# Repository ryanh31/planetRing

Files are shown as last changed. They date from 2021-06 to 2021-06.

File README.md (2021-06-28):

# planetRing v3_x
dmx stepper motor control
by ryan h\
for silovsky studios 2021

Lux Phantasmatis / Pavel Zustiak and Keith Skretch

Please refer to the included information guide for setup and use examples

Arduino Uno

DMX shield: https://www.digikey.com/en/products/detail/dfrobot/DFR0260/7087143 \
Dmx Serial Library: https://github.com/mathertel/DMXSerial \
based on this: https://sourceforge.net/projects/dmxlibraryforar/files/ \
arduino code provided 

Stepper Control using the AccelStepper Library: https://www.airspayce.com/mikem/arduino/AccelStepper/ \
Stepper Driver: DM860T https://www.omc-stepperonline.com/download/DM860T.pdf \
Stepper Motor: 34HE59-6004S https://www.omc-stepperonline.com/download/34HE59-6004S.pdf 

Limit switching / Auto Homing control using 8mm Magnetic Proximity Sensors: MAE-AP-1A \
https://cdn.automationdirect.com/static/specs/ip69kproxmag1218maf.pdf 

Software interface for Isadora 3.x & DMX with Lanbox or Enttec USB DMX \
Isadora Motor Control Index Patch provided.

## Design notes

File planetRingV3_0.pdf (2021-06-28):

# planetRing

## INFO GUIDE

planetRing-dmx stepper v3.0

Silovsky Studios 2021

## Planet/Ring Stepper Motor Control System with DMX512 & LED Control via Artnet

Software: Isadora 3.0 and Madmapper

info guide, code, hardware and controller system design by Ryan Holsopple
ryan.local@gmail.com

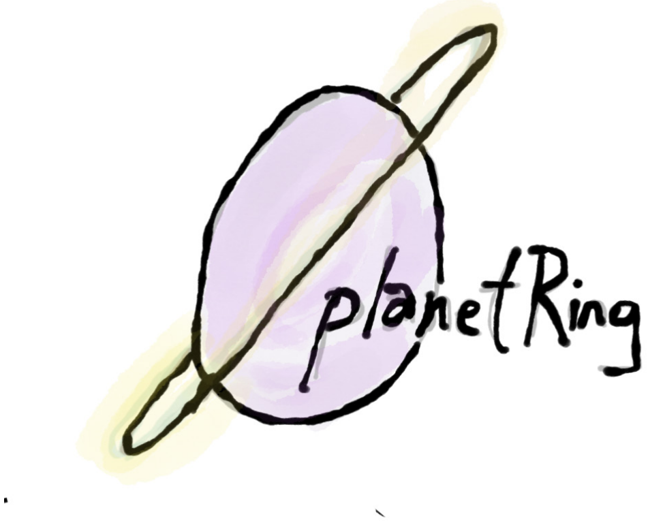
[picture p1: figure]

# Information Guide Index

### Part 1: DMX to Stepper Motor Control

System Diagram
DMX Wiring Diagram
Wiring Color Codes

Modes

Isadora Control

### Part 2: Artnet31 Network Information

Login and SSID information

LeDMX King

Artnet Information and Setup with MadMapper (TBD)

Isadora Syphon to MadMapper

### Part 3: Troubleshooting (working)

# Part 1: Stepper Motor Control with DMX system diagram

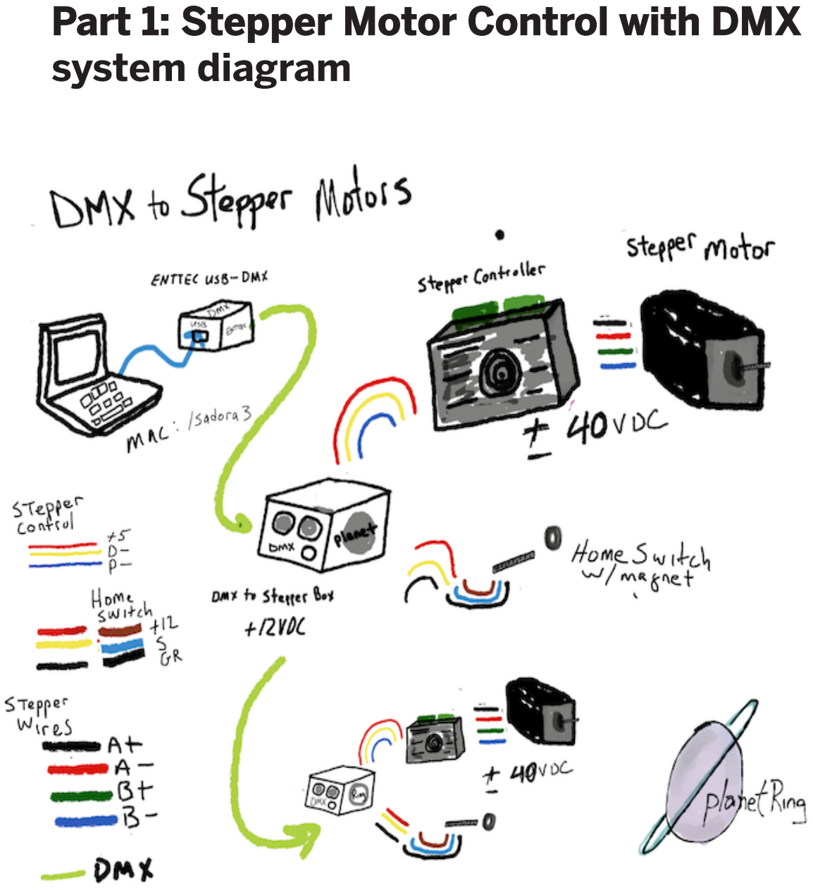
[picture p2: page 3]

# Stepper Motor Control with DMX DMX wiring diagram

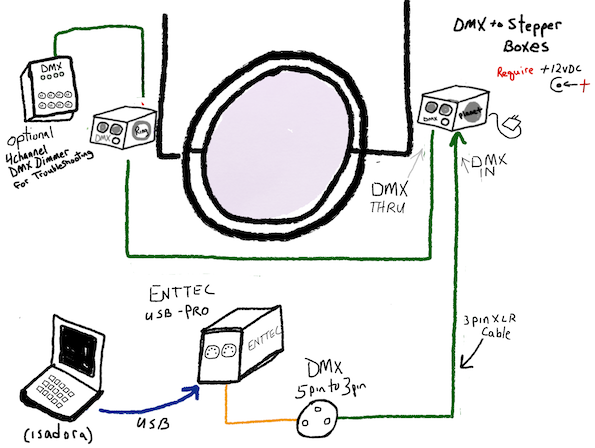
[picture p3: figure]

Stepper motor data sheet:
https://www.omc-stepperonline.com/download/34HE59-6004S.pdf

Stepper driver: DM860T https://www.omc-stepperonline.com/download/DM860T.pdf

Dip Switch Settings: 800 Steps, full power

1=OFF, 2=ON, 3=OFF, 4=ON, 5=OFF, 6=ON, 7=ON, 8=ON

WIRING COLOR SCHEMES
Stepper Controller, this is the same wiring for both motors.

Stepper MOTOR Controller (Black box with Fan):

Color code connections from Arduino Box to Stepper Controller

DIR- Yellow
DIR+ Red
PUL- Blue
PUL+ Red

Color code connections from Stepper Controller to MOTOR

A+ Black
A- Green
B+ Red
B- Blue
+ 45 vdc
- Ground

Home Position Proximity Sensor

Color code connections from Arduino Box to Stepper Controller

Red to Brown
Black to Black
Yellow to Blue

# Technical Info and Wiring Color Codes

# Wiring and Dip Switch Photos

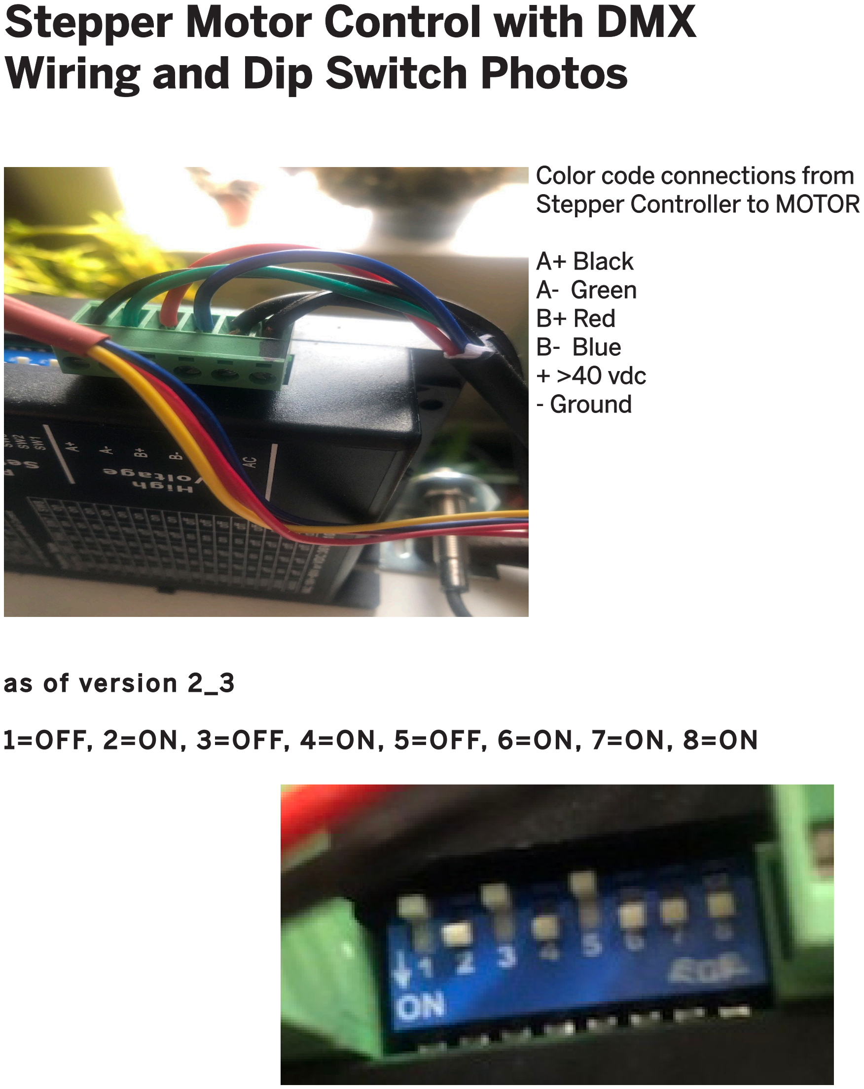
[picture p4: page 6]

Color code connections from Stepper Controller to MOTOR

A+ Black
A- Green
B+ Red
B- Blue
+ >40 vdc
- Ground

as of version 2_3

1=OFF, 2=ON, 3=OFF, 4=ON, 5=OFF, 6=ON, 7=ON, 8=ON

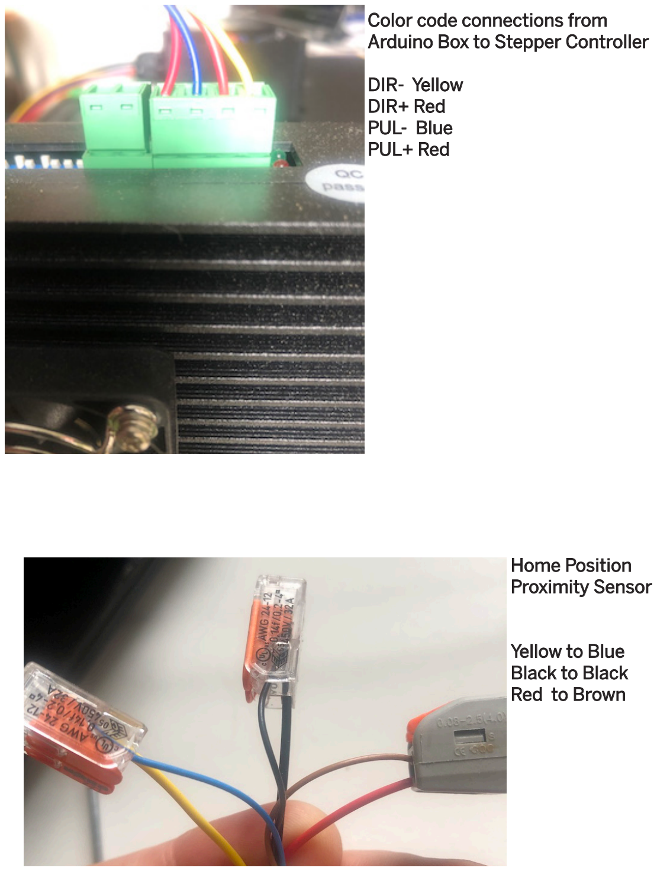
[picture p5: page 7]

Color code connections from Arduino Box to Stepper Controller

DIR- Yellow
DIR+ Red
PUL- Blue
PUL+ Red

Home Position
Proximity Sensor

Yellow to Blue
Black to Black
Red to Brown

# Stepper Motor Control

### with DMX in SITU

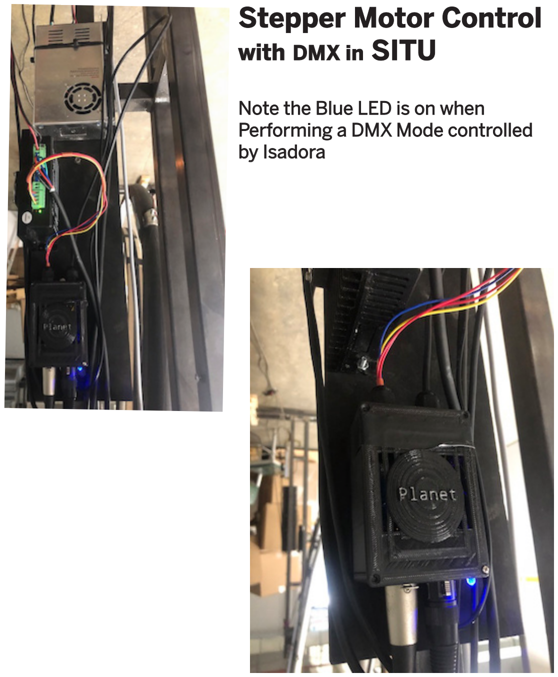
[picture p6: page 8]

Note the Blue LED is on when Performing a DMX Mode controlled by Isadora

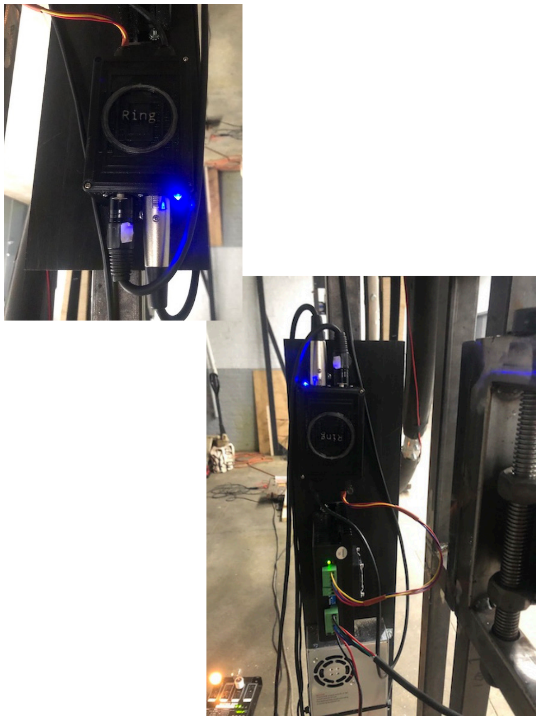
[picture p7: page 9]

Modes for PLANET / RING Motors

Mode 0: Stop Motors

Mode 1: Auto Home, rotate to home position
(planet and Ring Autohome in opposite directions)

Mode 2: Do 1 rotation with acceleration and deceleration
(in beta, count is not correct)

Mode 3: Do X rotations with acceleration/deceleration, where X is your value (in beta, count is not correct)

Mode 4: Accelerate to constant speed CW X, then, when triggered, back to stop, where X > 0 && <= full speed

Mode 5: Accelerate to constant speed Full Speed CCW X, then, when triggered, back to stop, where X > 0 && <= full speed

Mode 6: Accelerate to constant speed FUll Speed CW X, then, when triggered, back to stop, where X > 0 && <= full speed

Mode 7: Accelerate to constant speed CCW X, then, when triggered, back to stop, where X > 0 && <= full speed

Mode 8. Live Mode with Dynamic Position Control
Move to specific cardinal points, or degrees in between

Mode 9: Accelerate to Speed CW, Live Control
(in beta, ramping is unstable for faster speeds)

Mode 10 Accelerate to Speed CCW, Live Control

Transmit DMX with Isadora and an ENTTEC DMX USB Interface:

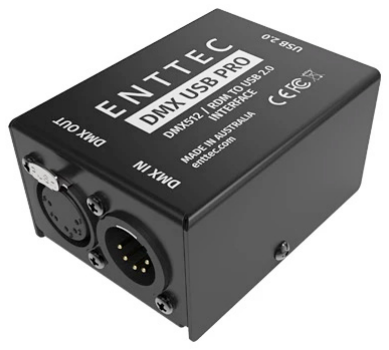
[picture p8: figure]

https://www.enttec.com/product/lighting-communication-protocols/dmx512/dmx-usb-interface/

To send DMX with Isadora using an Enttec DMX USB Pro:

Select and Enable the Device in the menu:

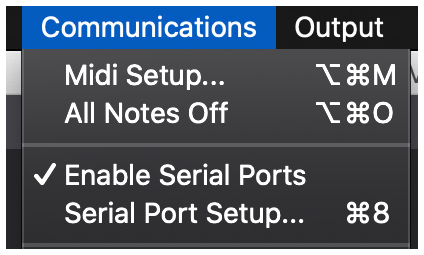
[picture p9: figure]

Communications>Serial Port Setup...

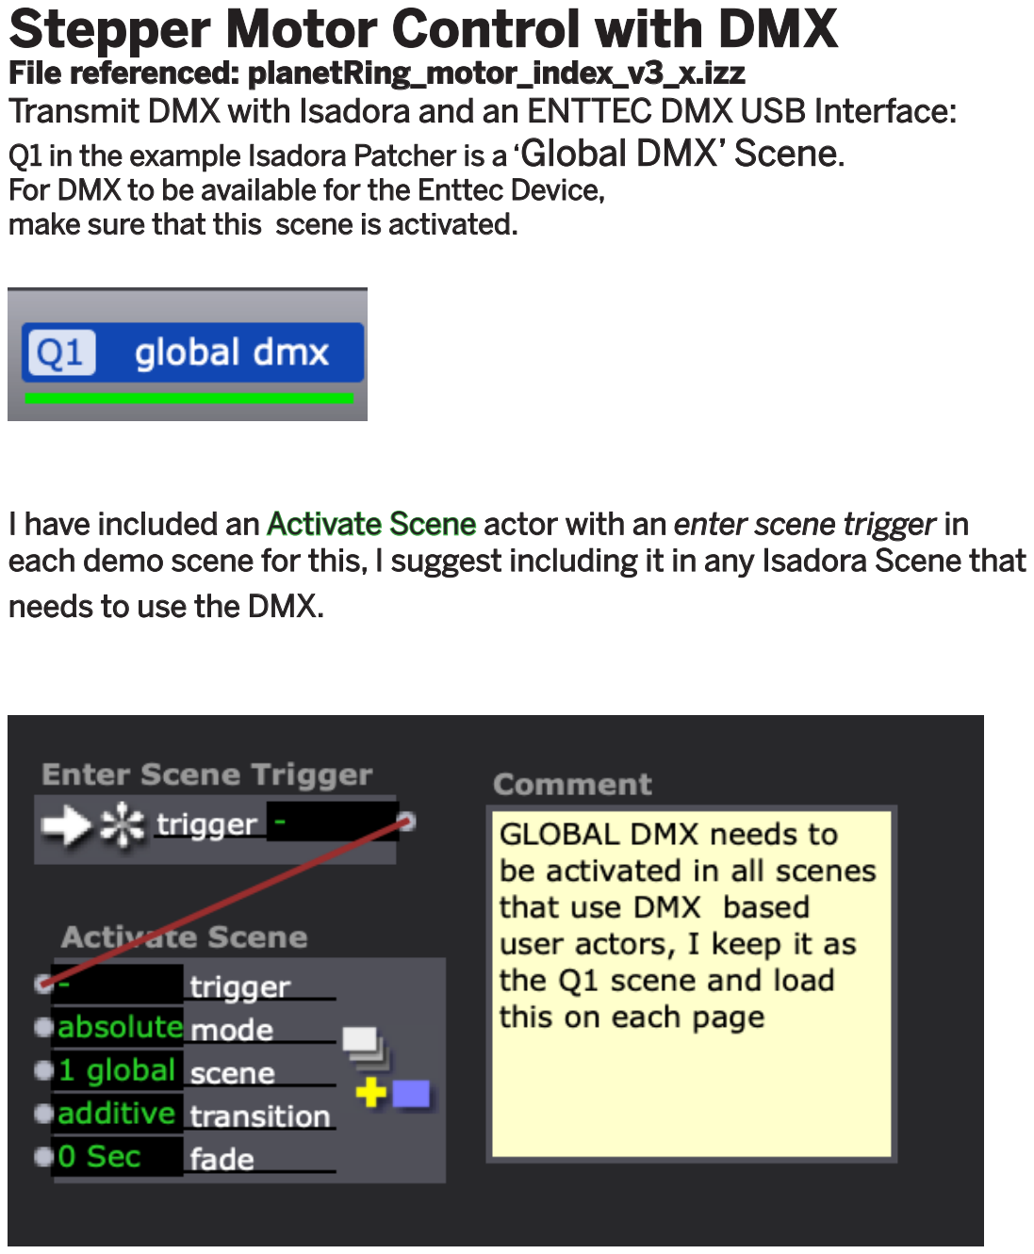
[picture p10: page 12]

File referenced: planetRing_motor_index_v3_x.izz
Transmit DMX with Isadora and an ENTTEC DMX USB Interface: Q1 in the example Isadora Patcher is a ‘Global DMX’ Scene.
For DMX to be available for the Enttec Device,
make sure that this scene is activated.

I have included an Activate Scene actor with an enter scene trigger in each demo scene for this, I suggest including it in any Isadora Scene that needs to use the DMX.

### Isadora Control

All Control Modes are encapsulated into Isadora User Actors.
Please DO NOT EDIT these User Actors, they have timing and values that are specific to the whole system.
These User Actors are labled and have an ENABLE input.
There are User Actors for each device PLANET / RING

NOTE: Only ONE User Actor for each device may be Enabled at the same time for the device to work Properly. If using multiple modes in one scene, make sure to enable/disable the User Actors as necessary. To make this easier I have included a Mode Stop/Start User actor. Remember to set the Enable State and to trigger the user actor.

### Mode 0: Stop Motors

Each example Scene (“Q”) that I provide uses an Enter Scene Trigger to Stop the Stepper motors.

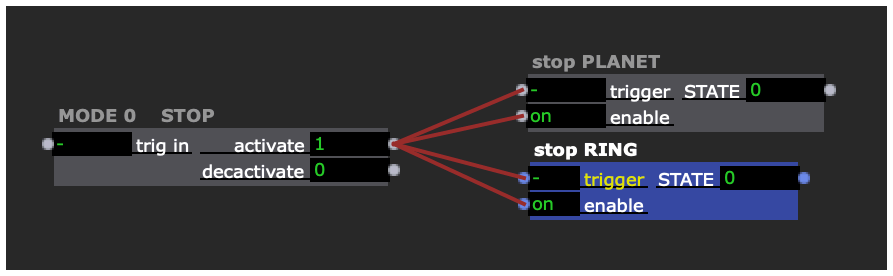
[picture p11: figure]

### Example Scene Q2:

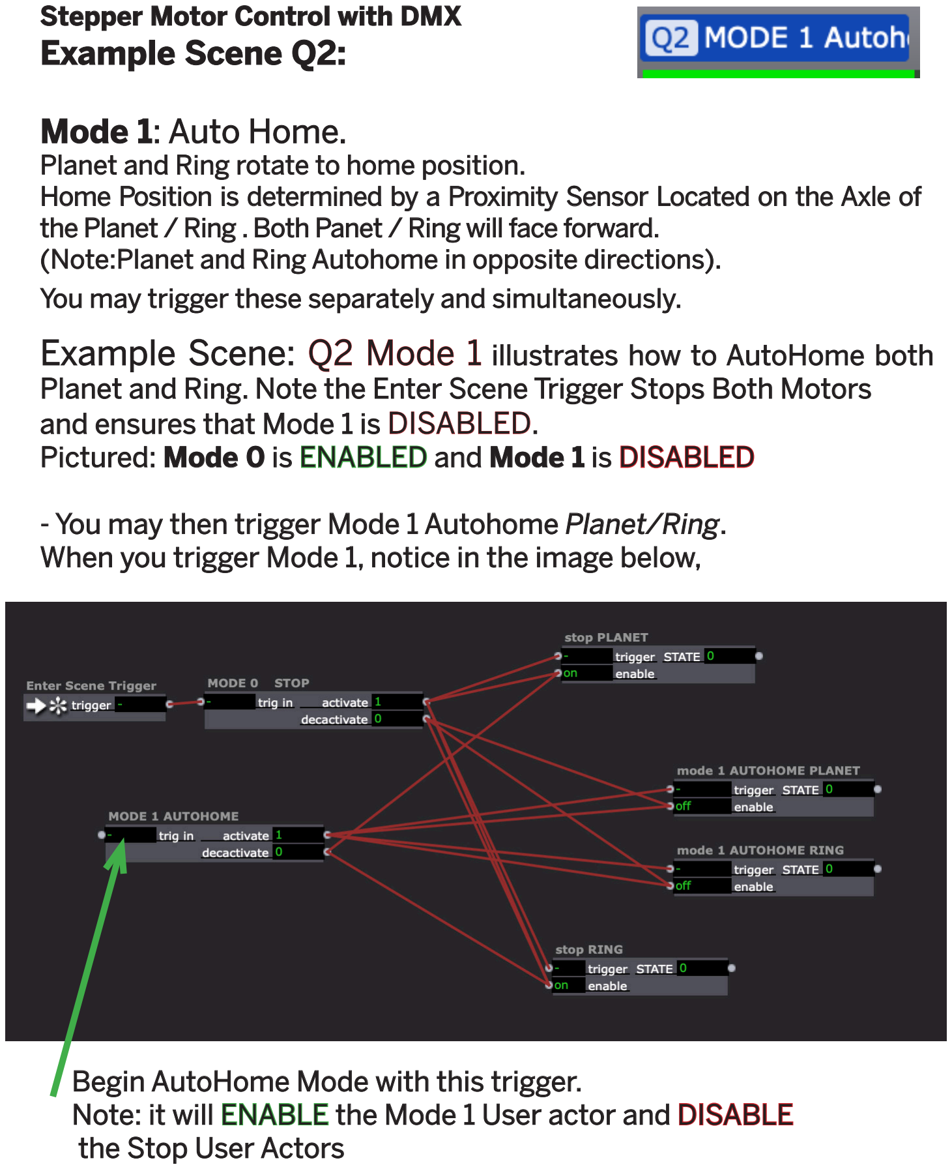
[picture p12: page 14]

Mode 1: Auto Home.
Planet and Ring rotate to home position.
Home Position is determined by a Proximity Sensor Located on the Axle of the Planet / Ring . Both Panet / Ring will face forward.
(Note:Planet and Ring Autohome in opposite directions).
You may trigger these separately and simultaneously.
Example Scene: Q2 Mode 1 illustrates how to AutoHome both Planet and Ring. Note the Enter Scene Trigger Stops Both Motors and ensures that Mode 1 is DISABLED.
Pictured: Mode 0 is ENABLED and Mode 1 is DISABLED
- You may then trigger Mode 1 Autohome Planet/Ring.
When you trigger Mode 1, notice in the image below,

Begin AutoHome Mode with this trigger.
Note: it will ENABLE the Mode 1 User actor and DISABLE the Stop User Actors

### Example Scene Q3:

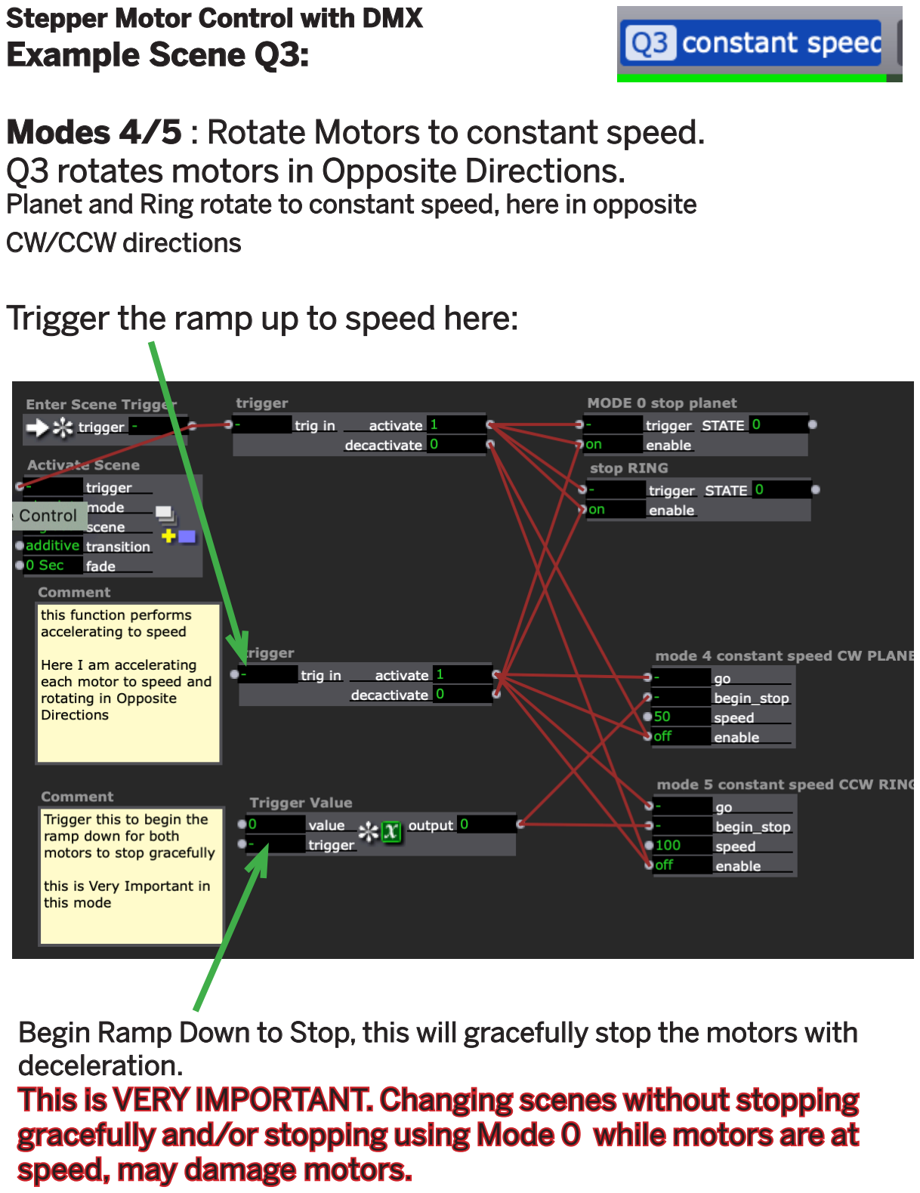
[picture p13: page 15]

Modes 4/5 : Rotate Motors to constant speed. Q3 rotates motors in Opposite Directions.
Planet and Ring rotate to constant speed, here in opposite CW/CCW directions

### Trigger the ramp up to speed here:

Begin Ramp Down to Stop, this will gracefully stop the motors with deceleration.
This is VERY IMPORTANT. Changing scenes without stopping gracefully and/or stopping using Mode 0 while motors are at speed, may damage motors.

### Example Scene Q4:

Modes 4/4: Rotate Motors in One Direction.
Planet and Ring rotate to constant speed, in the image below notice that both Mode 4 constant speed CW planet/Ring user actors are in use.

### Trigger the ramp up to speed here:

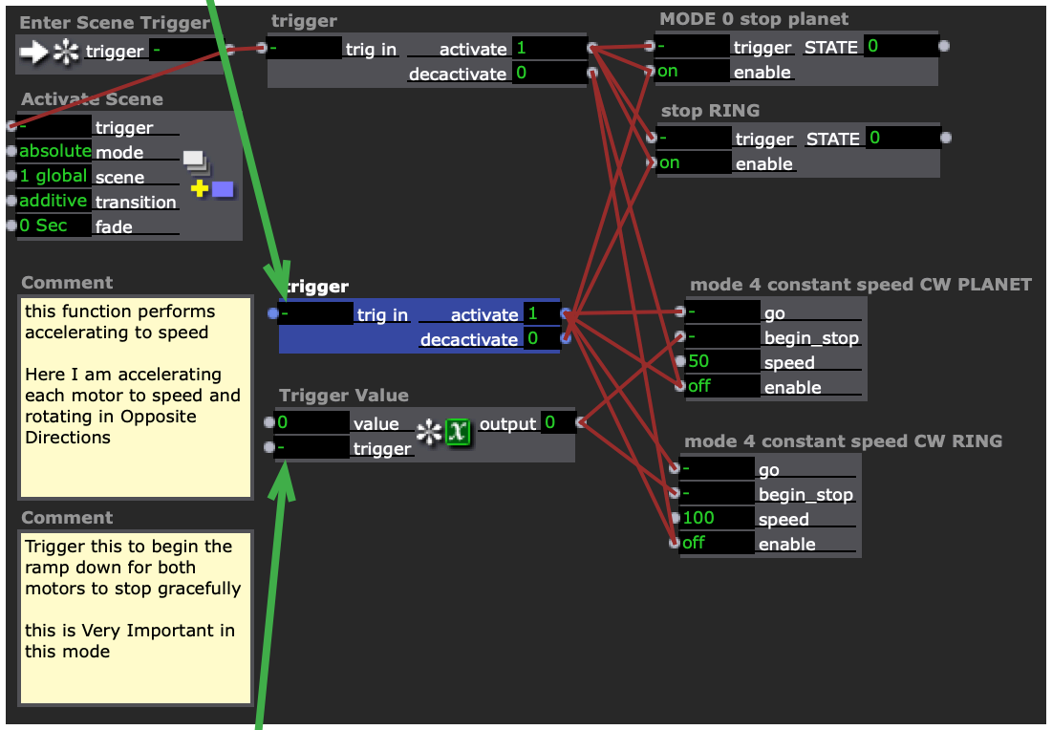
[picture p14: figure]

Begin Ramp Down to Stop, this will gracefully stop the motors with deceleration.
This is VERY IMPORTANT. Changing scenes without stopping gracefully and/or stopping using Mode 0 while motors are at speed, may damage motors.

### Example Scene Q5:

### Mode 8: Live Mode: Dynamic Position Control

Position and acceleration movements are posible on a 0-50.0 scale, floats are possible to acheive smaller steps.

### In the image below of Isadora Scene Q5, an

example of how to use Mode 8 Planet/Ring,

### Isadora Trigger Value actors are used to set positions in

the Mode 8 “position 1-50” user input.

### What I call ‘Cardinal Points’, clock positions are provided

0-3-6-9-12

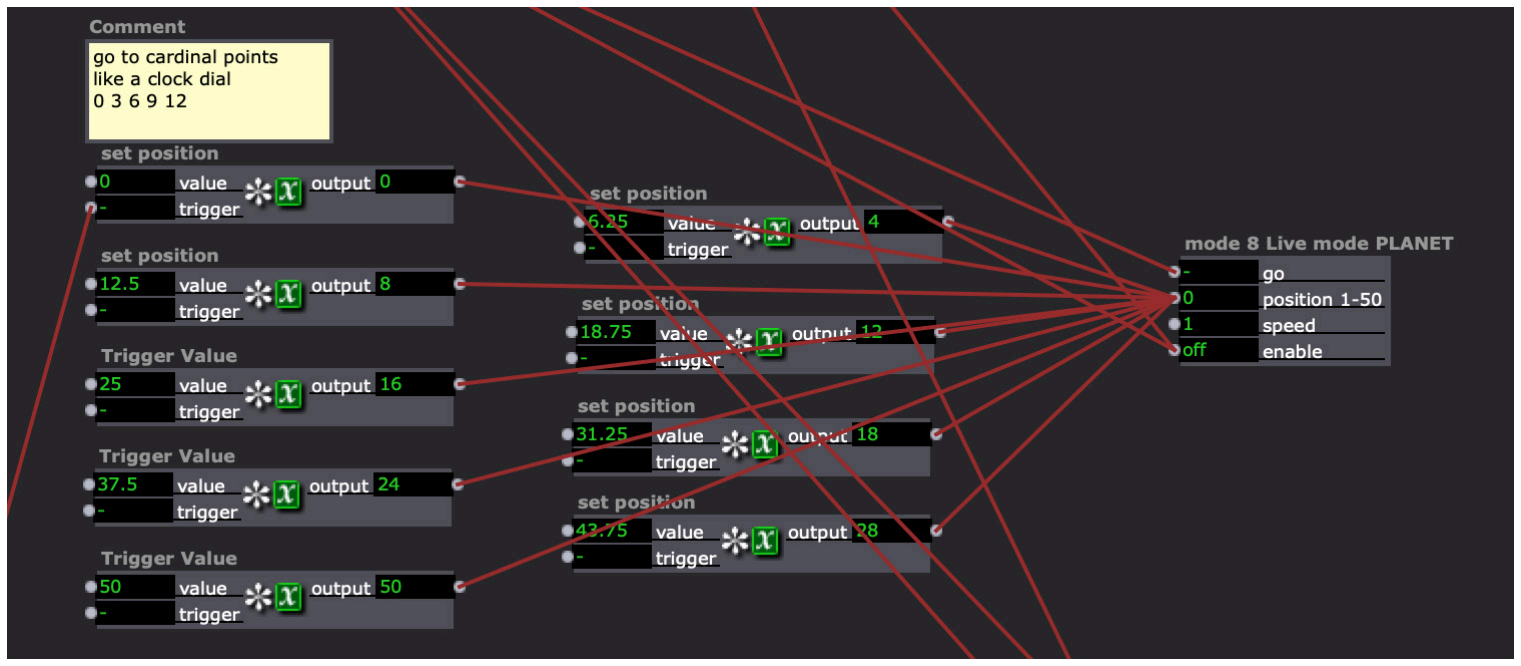
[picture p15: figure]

### Planet / Ring Indexes and DMX Test Mode

The INDEX SCENES Q6/Q7 provide all available Modes.

You can copy / paste these User Actor Modes (1-8) into other scenes, remember to add ENABLE / DISABLE logic to ensure the stepper motors will work correctly.

Modes 0, 1, 4, 5 & 8 have been prioritized for use with the current system.

Note Modes 2, 3, 6, & 7 are not fully developed and in a Beta stage. These MAY be used, but there are a few scaling issues and smoothing issues that make these modes less predictable. If interest in developing these modes increases, we can work to refine.

Test DMX: Scene Q8 acts as a dmx tester, blink channel 4. Use the provided DMX 4channel Dimmer Pack to monitor 4 channels of DMX signal. This Scene blinks channel 4.
NOTE: the DMX address can be changed in isadora and on the dimmer pack if higher channels wish to be chosen.

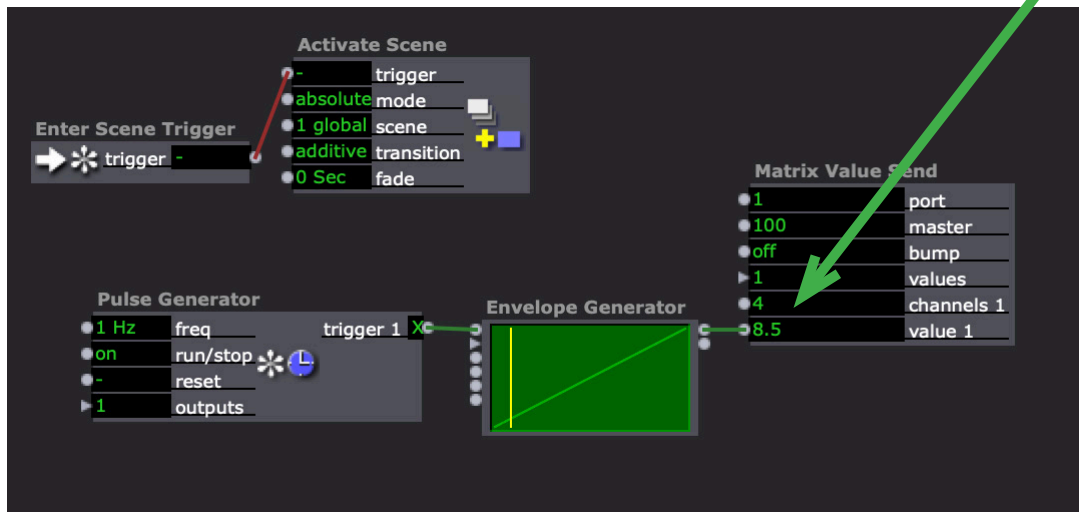
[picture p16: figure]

intentionally left blank

# Part 2: Artnet & Network Information

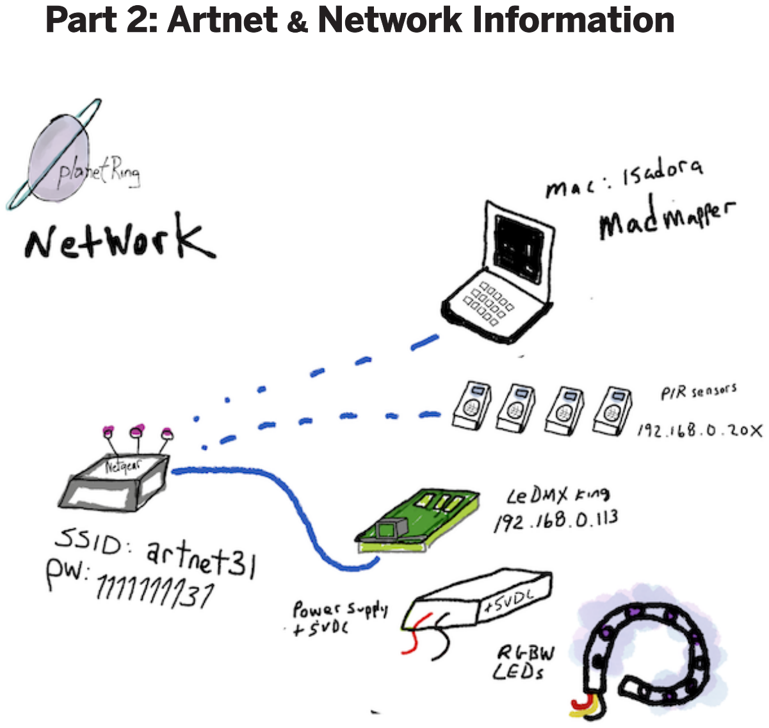
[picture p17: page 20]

# Network Information

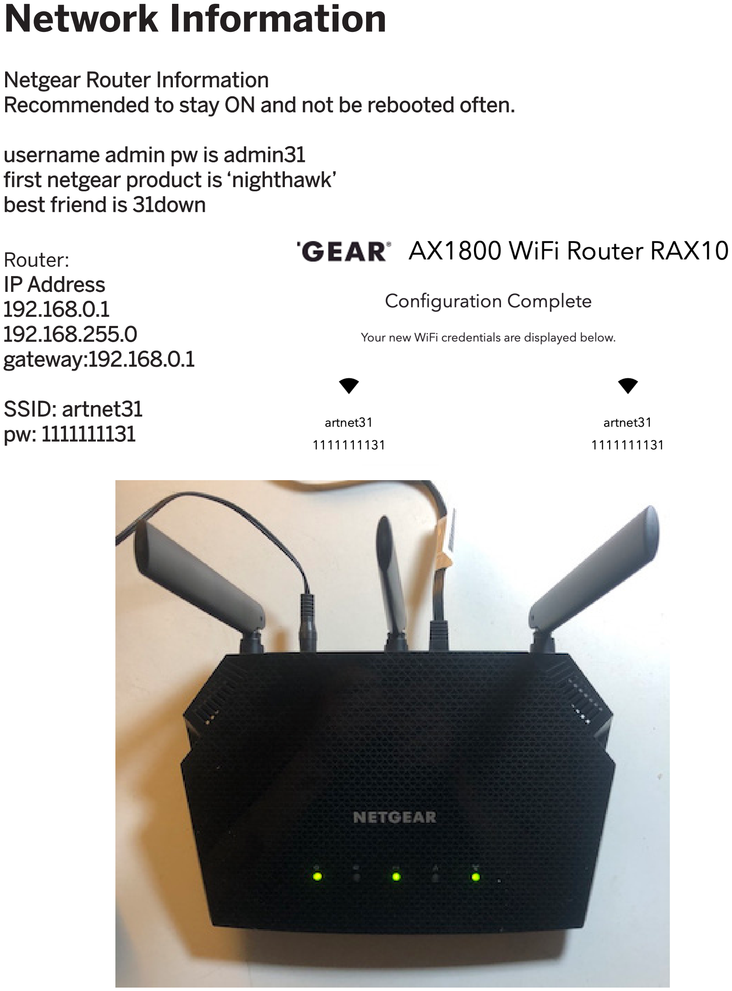
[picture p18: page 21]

Netgear Router Information
Recommended to stay ON and not be rebooted often.

username admin pw is admin31
first netgear product is ‘nighthawk’
best friend is 31down

Router:
IP Address
192.168.0.1
192.168.255.0
gateway:192.168.0.1

SSID: artnet31
pw: 1111111131

# Network

LeDMX4 Pro by DMX King:

IP address:
192.168.0.113
255.255.255.0

MADMAPPER ARTNET START UNIVERSE 0

more info and the manual
https://dmxking.com/led-pixel-control/ledmx4-pro

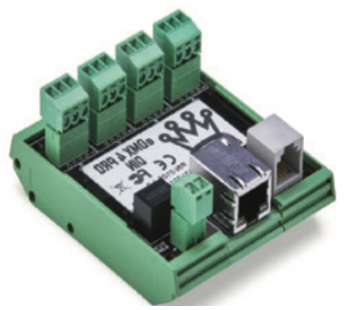
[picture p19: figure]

# Network

MADMAPPER:

ip address:
192.168.0.XXX
255.255.255.0

MADMAPPER ARTNET START UNIVERSE 0

install the LED Artnet Preferences File for DMX setup.
Included file: planetRing_madmapper_led_preferences_file.madled

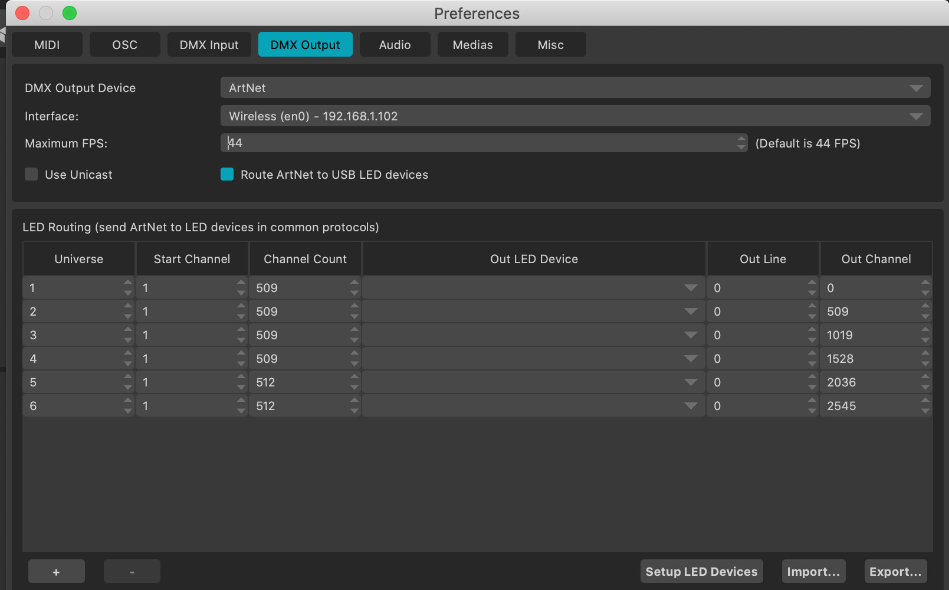
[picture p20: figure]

# artNet to LED Info

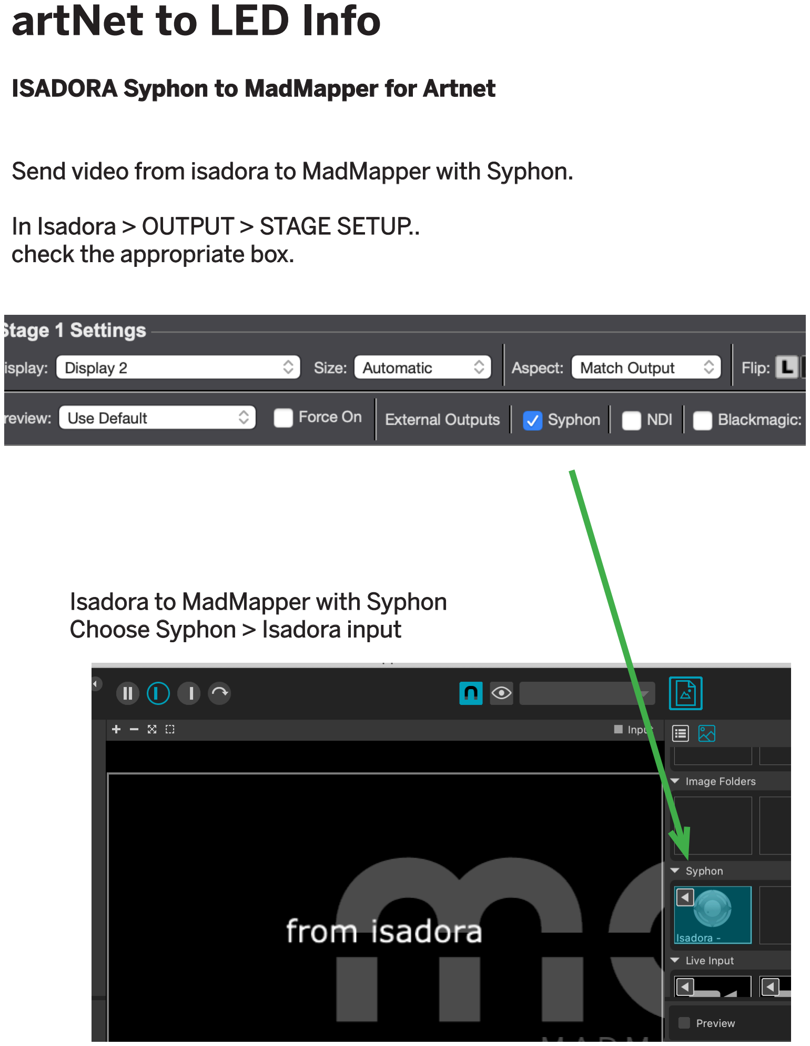
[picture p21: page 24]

ISADORA Syphon to MadMapper for Artnet

Send video from isadora to MadMapper with Syphon.

In Isadora > OUTPUT > STAGE SETUP..
check the appropriate box.

Isadora to MadMapper with Syphon Choose Syphon > Isadora input

intentionally left blank

intentionally left blank

# Part 4 Troubleshooting (working)

Artnet Troubleshooting:

are LEDs and DMX King device receiving power?

are the computer and LeDMX King devices on the artnet31 network?

Is MadMapper a Demo License?

Stepper Troubleshooting:

Are the steppers receiving power?

Are LEDs ON:

Controller will be green/Red? Planet or Ring boxes will have a Blue LED

Is the ENTTEC device Enabled in Isadora? Is the ENTTEC device sending DMX, you can use the provided dimmer at the end of the signal chaiin to test this.

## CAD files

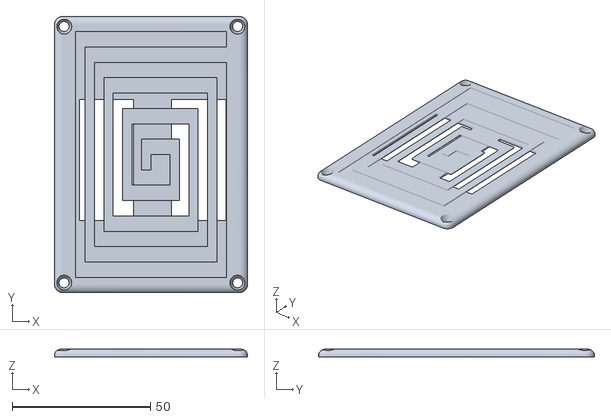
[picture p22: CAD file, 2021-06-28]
3d_print_files/dmx stepper 2.2(lid).stl
70.0 x 100.0 x 3.00

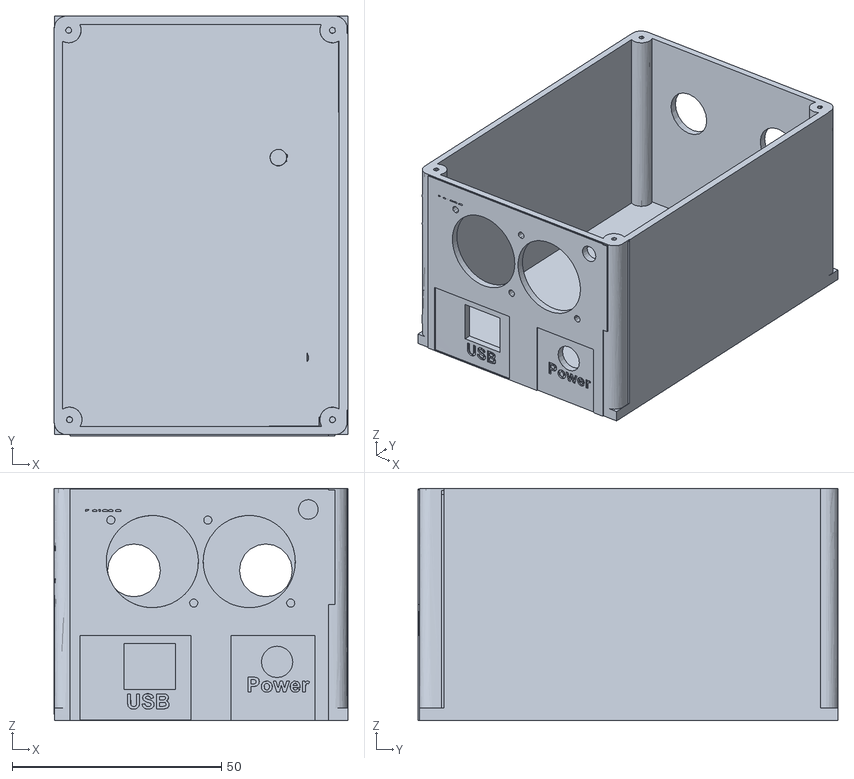
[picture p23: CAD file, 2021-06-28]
3d_print_files/dmx stepper 2.2(case).stl
70.1 x 100.3 x 55.5

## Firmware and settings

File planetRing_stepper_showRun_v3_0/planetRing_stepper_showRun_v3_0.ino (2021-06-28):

//2021 holsopple / silovsky  studios

// https://www.digikey.com/htmldatasheets/production/2306332/0/0/1/ctc-dra-10-1.html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
//https://www.omc-stepperonline.com/download/DM860T.pdf
//https://www.digikey.com/en/products/detail/dfrobot/DFR0260/7087143
//https://www.omc-stepperonline.com/download/DM860T.pdf
//8mm proximity sensor: MAE-AP-1A https://cdn.automationdirect.com/static/specs/ip69kproxmag1218maf.pdf

#include <AccelStepper.h>
#include <DMXSerial.h>


#define enable 13
#define dirPin 5 //dir-
#define stepPin 7  //pul-
#define motorInterfaceType 1
// Define a stepper and the pins it will use
AccelStepper stepper = AccelStepper(motorInterfaceType, stepPin, dirPin); // Defaults to AccelStepper::FULL4WIRE (4 pins) on 2, 3, 4, 5

const int LED =    13;  //
const int LED2 =    9;  // PWM output pin for testing


// variables for DMX start channel
int MaxDMXChannels = 9;
int DMXstartChan = 1 ;//set start channel DMX //planet == 1 //ring ==11

const int switchPin1 = 11;
int switchState1 = 0;         // variable for reading the pushbutton status

void setup()
{
  //DEFAULT DMX VALUES
  DMXSerial.init(DMXReceiver);

  for (int DMXchannel = DMXstartChan; DMXchannel < (DMXstartChan + 8); DMXchannel++) {
    // turn the pin on:
    DMXSerial.write(DMXchannel, 0);
    delay(1);
  }


  pinMode(dirPin, OUTPUT);
  pinMode(stepPin, OUTPUT);
  pinMode(enable, OUTPUT);


  // enable pwm outputs
  pinMode(LED,   OUTPUT); // sets the digital pin as output
  pinMode(switchPin1, INPUT_PULLUP);


  stepper.setMaxSpeed(400);
  stepper.setAcceleration(20);
}

void loop()
{

  int mode = DMXSerial.read(DMXstartChan);//DMX Channel 10 PLANET  DMX Start Channel 20 RING
  if ((mode == 0) ) { //0 isadora percent
    digitalWrite(LED, LOW);
    //stepper.setCurrentPosition(0);
  }
  // MODE 1  autohome
  if ((mode > 0) && (mode < 5 )) { //1 isadora percent
    digitalWrite(LED, HIGH);
    stepper.setCurrentPosition(0);

    do {
      // read the state of the pushbutton value:
      switchState1 = digitalRead(switchPin1);

      stepper.moveTo(-3000);//1600 FULL ROTATION
      stepper.setMaxSpeed(40);
      stepper.setAcceleration(10);
      stepper.run();
    }
    while (switchState1 == LOW);
    digitalWrite(LED, LOW);
    stepper.stop();
    stepper.setCurrentPosition(0);
    delay(100);
  }



  //  MODE 2
  else if ((mode == 5 )) { //isadora 2 %
    digitalWrite(LED, HIGH);
    stepper.setCurrentPosition(0);
    do {

      if (DMXSerial.read(DMXstartChan + 2) > 127) {
        stepper.moveTo(1600);//one rotation
        stepper.setMaxSpeed(map(DMXSerial.read(DMXstartChan + 3), 0, 255, 0, 800));
        stepper.setAcceleration(20);
        stepper.run();
      }

      else {
        stepper.moveTo(-1600);//one rotation
        stepper.setMaxSpeed(map(DMXSerial.read(DMXstartChan + 3), 0, 255, 0, 800));
        stepper.setAcceleration(20);
        stepper.run();
      }
    }
    while ( DMXSerial.read(DMXstartChan + 1) > 10);

  }



  //  MODE 3
  else if ((mode > 5 ) && (mode < 10)) { //isadora 3 %
    digitalWrite(LED, HIGH);
    stepper.setCurrentPosition(0);
    do {

      if (DMXSerial.read(DMXstartChan + 2) > 127) {
        stepper.moveTo(800 * DMXSerial.read(DMXstartChan + 4));//one rotation
        stepper.setMaxSpeed(map(DMXSerial.read(DMXstartChan + 3), 0, 255, 0, 800));
        stepper.setAcceleration(20);
        stepper.run();
      }

      else {
        stepper.moveTo(-800 * DMXSerial.read(DMXstartChan + 4));//one rotation
        stepper.setMaxSpeed(map(DMXSerial.read(DMXstartChan + 3), 0, 255, 0, 800));
        stepper.setAcceleration(20);
        stepper.run();
      }
    }
    while ( DMXSerial.read(DMXstartChan + 1) > 10);

  }





  //  MODE 4  GO TO CONSTANT SPEED,CHECK, DIRECTION, SPEED
  else if ((mode > 10 ) && (mode < 20 )) { //isadora 2 %
    digitalWrite(LED, HIGH);
    stepper.setCurrentPosition(0);
    do {

      if (DMXSerial.read(DMXstartChan + 2) > 10) {
        stepper.moveTo(stepper.currentPosition() + 8000);
        stepper.setMaxSpeed(map(DMXSerial.read(DMXstartChan + 3), 0, 255, 0, 800));
        stepper.setAcceleration(20);
        stepper.run();
      }

    }
    while ( DMXSerial.read(DMXstartChan + 4) < 10);
    do {
      stepper.moveTo(stepper.currentPosition() - 0);
      stepper.setMaxSpeed(map(DMXSerial.read(DMXstartChan + 3), 0, 255, 0, 800));
      stepper.setAcceleration(20);
      stepper.run();
    }

    while (DMXSerial.read(DMXstartChan + 1) > 10);
    // Serial.println("nada");
  }




  //  MODE 5  GO TO CONSTANT SPEED,CHECK, DIRECTION, SPEED counterclockwize
  else if ((mode > 20 ) && (mode < 30 )) { //isadora 2 %
    digitalWrite(LED, HIGH);
    stepper.setCurrentPosition(0);
    do {

      if (DMXSerial.read(DMXstartChan + 2) > 127) {
        stepper.moveTo(stepper.currentPosition() - 8000);
        stepper.setMaxSpeed(map(DMXSerial.read(DMXstartChan + 3), 0, 255, 0, 800));
        stepper.setAcceleration(20);
        stepper.run();
      }

    }
    while ( DMXSerial.read(DMXstartChan + 4) < 10);
    do {
      stepper.moveTo(stepper.currentPosition() + 0);
      stepper.setMaxSpeed(map(DMXSerial.read(DMXstartChan + 3), 0, 255, 0, 800));
      stepper.setAcceleration(6);
      stepper.run();
    }

    while (DMXSerial.read(DMXstartChan + 2) != 0);
    // Serial.println("nada");
  }

  //NEW MODE 6
  ///MODE 6 LIVE RUN TO SPEED
  else if ((mode == 79)) { //isadora31
    digitalWrite(LED, HIGH);
    stepper.setCurrentPosition(0);
    do {

      if (DMXSerial.read(DMXstartChan + 2) > 127) {
        stepper.moveTo(stepper.currentPosition() + 6000);
        stepper.setMaxSpeed(map(DMXSerial.read(DMXstartChan + 3), 0, 255, 0, 600));
        stepper.setAcceleration(6);
        stepper.run();
      }

    }
    while ( DMXSerial.read(DMXstartChan + 4) < 10);
    do {
      stepper.moveTo(stepper.currentPosition() + 0);
      stepper.setMaxSpeed(map(DMXSerial.read(DMXstartChan + 3), 0, 255, 0, 600));
      stepper.setAcceleration(6);
      stepper.run();
    }

    while (DMXSerial.read(DMXstartChan + 2) != 0);
    // Serial.println("nada");
  }


  //NEW MODE 7 RUN TO FAST CCW
  else if ((mode > 30 && (mode < 40))) { //ISADORA 15
    digitalWrite(LED, HIGH);
    stepper.setCurrentPosition(0);
    do {

      if (DMXSerial.read(DMXstartChan + 2) > 127) {
        stepper.moveTo(stepper.currentPosition() - 6000);
        stepper.setMaxSpeed(map(DMXSerial.read(DMXstartChan + 3), 0, 255, 0, 600));
        stepper.setAcceleration(6);
        stepper.run();
      }

    }
    while ( DMXSerial.read(DMXstartChan + 4) < 10);
    do {
      stepper.moveTo(stepper.currentPosition() + 0);
      stepper.setMaxSpeed(map(DMXSerial.read(DMXstartChan + 3), 0, 255, 0, 600));
      stepper.setAcceleration(6);
      stepper.run();
    }

    while (DMXSerial.read(DMXstartChan + 2) != 0);
    // Serial.println("nada");
  }


  ///NEW MODE 9 LIVE RUN TO SPEED
  else if ((mode > 40 && (mode < 50))) { //ISADORA 18
    digitalWrite(LED, HIGH);
    //stepper.setSpeed(DMXSerial.read(DMXstartChan + 3) * 1 )); //speedVal
    stepper.setSpeed(DMXSerial.read(DMXstartChan + 3) * 1); //speedVal
    stepper.runSpeed();
    stepper.run();
  }


  //NEW MODE 10 RUN TO speed
  else if ((mode > 50 && (mode < 60))) { //ISADORA 22
    stepper.setCurrentPosition(0);

    digitalWrite(LED, HIGH);
    stepper.setSpeed(DMXSerial.read(DMXstartChan + 3) * -1); //speedVal
    stepper.runSpeed();
    stepper.run();

  }


  //new mode 11 autohome 2
  else if ((mode > 60 && (mode < 70))) { //ISADORA 26

    digitalWrite(LED, HIGH);
    stepper.setCurrentPosition(0);

    do {
      // read the state of the pushbutton value:
      switchState1 = digitalRead(switchPin1);

      stepper.moveTo(4000);//1600 FULL ROTATION
      stepper.setMaxSpeed(60);
      stepper.setAcceleration(20);
      stepper.run();
      //  stepper2.run();
    }
    while (switchState1 == LOW);
    digitalWrite(LED, LOW);
    stepper.stop();
    stepper.setCurrentPosition(0);
    delay(100);
  }

  else if (mode > 80 ) { //isadora 2 %    digitalWrite(LED, HIGH);
    stepper.setCurrentPosition(0);
    digitalWrite(LED, HIGH);

    do {
      //(DMXSerial.read(DMXstartChan + 2) > 127)


      stepper.moveTo(map(DMXSerial.read(DMXstartChan + 4), 0, 100, 0, 800));
      stepper.setMaxSpeed(800);//was 800
      stepper.setAcceleration(20);
      stepper.run();

    }
    while ( DMXSerial.read(DMXstartChan + 1) > 10);

  }




  delay(1);        // delay in between reads for stability
}
